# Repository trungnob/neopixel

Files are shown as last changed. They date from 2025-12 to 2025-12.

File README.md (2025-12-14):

# ESP8266 LED Matrix Controller & Pattern Designer

This project drives a **32x32 LED Matrix** (composed of four 8x32 WS2812B panels) using an ESP8266 (Wemos D1 Mini). It features a web-based **Pattern Designer** for creating and uploading custom pixel art and animations.

## Features
- **Hardware Support**: Configured for a 32x32 grid (1024 LEDs) using 4x 8x32 panels in a vertical stack.
- **Web Interface**: 
  - **Control Panel**: Switch between 40+ pre-defined patterns (Rainbow, Fire, Matrix, etc.).
  - **Pattern Designer**: Draw custom pixel art, create animations, and scroll text.
  - **Static Mode**: Display static images (Speed 0).
- **OTA Updates**: Flash new firmware wirelessly.
- **Mechanical Parts**: 3D printable housing for the panels.

## Directory Structure
- `src/`: Firmware source code (C++).
- `web/`: Web interface (`pattern-designer.html`).
- `mechanical/`:
  - `stl/`: 3D printable files (Housing, Mounts).
  - `scad/`: OpenSCAD source files for the housing.
- `scripts/`: Build and utility scripts.

## Getting Started

### 🚀 Quick Start (Recommended)
Run the automated setup script to configure Wi-Fi, install dependencies, and flash the device:
```bash
./scripts/quickstart.sh
```

### Manual Setup
If you prefer to set up everything manually:

### Prerequisites
- Python 3
- `pip`
- `make` (optional, but recommended)

### 1. Setup Environment
Run the bootstrap script to create a virtual environment and install PlatformIO:
```bash
make deps
# Or manually: ./scripts/bootstrap.sh
```

### 2. Configure Secrets
1. Copy the secrets template:
   ```bash
   cp config/secrets.env.example config/secrets.env
   ```
2. Edit `config/secrets.env` and add your Wi-Fi credentials (`WIFI_SSID` and `WIFI_PASSWORD`).
3. Generate OTA credentials:
   ```bash
   make ota-init HOST=192.168.1.130
   ```

### 3. Build and Upload Firmware
**First time (USB):**
Connect your ESP8266 via USB.
```bash
make upload PORT=/dev/ttyUSB0
```
*(Note: `PORT` might vary, e.g., `/dev/ttyACM0`)*

**Subsequent updates (OTA):**
```bash
make upload-ota HOST=192.168.1.130
```

### 4. Run the Pattern Designer
The Pattern Designer runs locally on your computer and communicates with the ESP8266.
```bash
python3 server.py
```
Open your browser to: [http://localhost:8000/pattern-designer.html](http://localhost:8000/pattern-designer.html)

**Note:** Ensure your computer is on the same Wi-Fi network as the ESP8266. The web interface proxies requests to the ESP8266 IP defined in `server.py` (default `192.168.1.130`).

## Mechanical Parts
3D printable files are located in `mechanical/stl/`.
- **Housing**: `8x32_housing_left.stl`, `8x32_housing_right.stl`
- **Stacked Batch**: `8x32_housing_stack.stl` (3x Left Half, matches original production file)
- **Source**: OpenSCAD files in `mechanical/scad/`.

To regenerate the STLs from source:
```bash
make mechanical
```

## Development
- **Build**: `make build`
- **Clean**: `make clean`
- **Monitor Serial**: `make monitor PORT=/dev/ttyUSB0`

## License
MIT License.

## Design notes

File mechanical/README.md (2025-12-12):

# 8×32 LED Panel Housing

3D printable housing for flexible 8×32 LED matrix panels (320mm × 80mm).

Panel Reference

## 📐 Panel Specifications

- **Size**: 8 rows × 32 columns (256 LEDs total)
- **Dimensions**: 320mm × 80mm (~12.6" × 3.15")
- **Thickness**: ~1.5mm flexible PCB
- **Connectors**: Multiple JST connectors along panel

## 🎯 Housing Features

- **Thin profile**: Only 8mm deep
- **Front LED channel**: 2mm shallow groove holds panel flat
- **Wire routing**: Back channels and exit holes for connectors
- **Mounting**: 4× M3 holes at corners for hanging/attaching
- **Weight reduction**: Hollow cavity reduces material use

## 📁 Files

### Full Housing (requires large printer)
- `8x32_panel_housing.scad` - Single piece design (324mm long)
- Requires printer with ≥ 324mm × 84mm build area

### Split Housing (for smaller printers)
- `8x32_housing_split.scad` - Two-piece design (162mm each)
- For printers with < 324mm beds
- Includes alignment pins for easy assembly

## 🖨️ Print Settings

```
Layer Height:    0.2mm
Infill:          20%
Supports:        None
Orientation:     Face down (wire channels facing up)
Material:        PLA or PETG
```

**Full housing**: ~3-4 hours  
**Split housing**: ~2 hours per half

## 🔨 Assembly

### Option 1: Full Housing
1. Print `8x32_panel_housing.scad`
2. Insert LED panel from front
3. Route wires through back holes
4. Mount using corner M3 holes

### Option 2: Split Housing
1. Print both halves from `8x32_housing_split.scad`
2. Insert LED panel into left half
3. Align right half using pins
4. Join with CA glue or epoxy
5. Optional: Add screw through split for strength
6. Route wires and mount

## ⚙️ Customization

Edit the SCAD files to adjust:

```scad
// Panel fit
panel_length = 320;          // Your panel length
panel_width = 80;            // Your panel width

// Wire routing
wire_hole_diameter = 6;      // Connector size
wire_hole_positions = [...]; // Add/move holes

// Housing depth
housing_depth = 8;           // Make deeper if needed

// Mounting holes
mounting_hole_dia = 4;       // M3 = 4mm, M4 = 5mm
```

## 💡 Tips

**If wires don't fit through holes:**
- Increase `wire_hole_diameter` to 8mm or 10mm
- Add more holes at connector positions

**If panel is loose:**
- Add thin foam tape or silicone dots
- Increase `led_channel_depth` slightly

**For wall mounting:**
- Print with 100% infill near mounting holes
- Use M3 × 10mm screws into wall anchors

**For desk stand:**
- Add triangular supports to back
- Use rubber feet to prevent sliding

## 📦 Materials Needed

- PLA or PETG filament (~50g)
- LED panel (8×32, 320mm × 80mm)
- Optional: 4× M3 screws for mounting
- Optional: CA glue (for split version)
- Optional: Foam tape for panel security

## 🎨 Variants You Can Make

1. **Deeper housing** - increase `housing_depth` for electronics
2. **Diffuser mount** - add front lip for acrylic diffuser
3. **Stackable** - add alignment features for multiple panels
4. **Angled mount** - modify for tilted wall display

## 🚀 Quick Start

```bash
# Export full housing
cd /home/trungnob/neopixel/mechanical
openscad -o 8x32_housing.stl 8x32_panel_housing.scad

# Or export split (left half)
openscad -D "is_left_half=true" -o 8x32_left.stl 8x32_housing_split.scad

# Export split (right half)  
openscad -D "is_left_half=false" -o 8x32_right.stl 8x32_housing_split.scad
```

## 📏 Dimensions Reference

| Component | Measurement |
|---|---|
| Panel Length | 320mm (12.59in) |
| Panel Width | 80mm (3.15in) |
| Panel Thickness | ~1.5mm |
| Housing Length | 324mm |
| Housing Width | 84mm |
| Housing Depth | 8mm |
| Weight (printed) | ~40-50g |

Perfect for LED matrix displays, digital signs, or decorative lighting!

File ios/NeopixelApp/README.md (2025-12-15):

# Neopixel iOS App

This folder contains the Swift source files for the **NeopixelApp** iOS application.

## How to use
1. Open Xcode on your Mac.
2. Choose **File → New → Project…** → **App** → **SwiftUI**.
3. Name the project **NeopixelApp** and set the Interface to **SwiftUI**, Life Cycle to **UIKit App Delegate**, Language to **Swift**.
4. When the project is created, replace the automatically generated files with the ones in this folder:
   - `AppDelegate.swift`
   - `SceneDelegate.swift`
   - `ContentView.swift`
   - `PatternGrid.swift`
   - `NetworkManager.swift`
5. Add the `Info.plist` entry `NSAppTransportSecurity` → `NSAllowsArbitraryLoads` = `YES` (or edit the existing Info.plist).
6. Build and run on your iPhone (or Simulator). The app will discover ESP8266 devices via Bonjour (`_neopixel._tcp`) and let you control the LED matrix.

## mDNS on the ESP8266
Add the following snippet to `src/main.cpp` **after** `ArduinoOTA.begin();` and re‑upload the firmware:
```cpp
if (MDNS.begin("neopixel-controller")) {
    MDNS.addService("neopixel", "tcp", 80);
    Serial.println("mDNS responder started");
}
```
The device will appear as `neopixel-controller.local` and be listed automatically in the app.

Enjoy!

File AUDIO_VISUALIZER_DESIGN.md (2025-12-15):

# Audio Visualizer Data Flow

## System Architecture

```
┌─────────────────────────────────────────────────────────────────────────────┐
│                        AUDIO VISUALIZER DATA FLOW                           │
└─────────────────────────────────────────────────────────────────────────────┘

┌──────────────┐
│   YouTube/   │
│   Spotify/   │
│   Any App    │
└──────┬───────┘
       │ Audio Output
       ▼
┌──────────────────────────────────────────────────────────────────────────┐
│                            PipeWire Audio System                          │
│                                                                          │
│  ┌─────────────────────┐                                                 │
│  │  visualizer_sink    │◄─── Apps send audio here (set as default)       │
│  │  (Null Sink)        │                                                 │
│  └──────────┬──────────┘                                                 │
│             │                                                            │
│             │ .monitor (realtime capture)                                │
│             │                                                            │
│             ├───────────────────────────────┐                            │
│             │                               │                            │
│             ▼                               ▼                            │
│  ┌──────────────────────┐     ┌─────────────────────────┐               │
│  │  parec (capture)     │     │  module-loopback        │               │
│  │  --latency-msec=1    │     │  latency_msec=1         │               │
│  └──────────┬───────────┘     └──────────┬──────────────┘               │
│             │                            │                               │
│             │ ◄──── MEASUREMENT POINT    │                               │
│             │       (1.4s includes       │                               │
│             │        human reaction)     │                               │
│             │                            │                               │
└─────────────┼────────────────────────────┼───────────────────────────────┘
              │                            │
              │ Raw PCM Audio              │ Delayed Audio
              ▼                            ▼
┌─────────────────────────┐    ┌─────────────────────────┐
│  lowlatency_visualizer  │    │  HDMI Output            │
│  (Python Script)        │    │  (alsa_output...hdmi)   │
│                         │    │                         │
│  ┌───────────────────┐  │    │  ┌───────────────────┐  │
│  │  FFT Processing   │  │    │  │  Speakers/TV      │  │
│  │  (scipy.fft.rfft) │  │    │  └───────────────────┘  │
│  └─────────┬─────────┘  │    └─────────────────────────┘
│            │            │
│  ┌─────────▼─────────┐  │
│  │  32 Frequency     │  │
│  │  Bins (40-16kHz)  │  │
│  └─────────┬─────────┘  │
│            │            │
│  ┌─────────▼─────────┐  │
│  │  LED Mapping      │  │
│  │  XY() function    │  │
│  └─────────┬─────────┘  │
│            │            │
└────────────┼────────────┘
             │ UDP Packet (3072 bytes)
             ▼
┌─────────────────────────┐
│  ESP8266 (192.168.1.130)│
│  Port 4210              │
│                         │
│  ┌───────────────────┐  │
│  │  FastLED Library  │  │
│  │  WS2812B Driver   │  │
│  └─────────┬─────────┘  │
└────────────┼────────────┘
             │ Data Signal
             ▼
┌─────────────────────────┐
│  32x32 LED Matrix       │
│  (4 × 8x32 Panels)      │
│  1024 WS2812B LEDs      │
└─────────────────────────┘
```

## Latency Measurement

The **1.43 second** was measured using `latency_test.py`:

```
Test data:
1.33s | 0.796 | Music still playing
1.44s | 0.000 | Silence detected
─────────────────────────────────────
Drop time: 1.44 - 1.33 = 0.11 seconds
```

### What the measurement shows:

```
┌─────────────────────────────────────────────────────────────────────┐
│ 0.0s                           1.33s                    1.44s       │
│  │                               │                        │         │
│  │◄─── Human Reaction Time ─────►│◄── Audio Latency ────►│         │
│  │     (ENTER → click pause)     │    (~110ms)           │         │
│  │         ~1.33 seconds         │                        │         │
│  │                               │                        │         │
│  ▼                               ▼                        ▼         │
│ [Press ENTER]              [Click Pause]          [parec sees 0]   │
│              in terminal          on YouTube                        │
└─────────────────────────────────────────────────────────────────────┘
```

### Latency Breakdown

| Component | Latency |
|---|---|
| Human reaction (ENTER → click pause) | ~1330ms |
| **Actual audio latency** | **~110ms** |
| FFT + LED mapping | ~0.2ms |
| UDP over WiFi | ~5-10ms |
| ESP8266 → LEDs | ~30ms |
| **Total audio → LED (theoretical)** | **~150ms** |

## ⚠️ Unresolved Issue: 7 Second Delay

When running `lowlatency_visualizer.py`, there's still a ~7 second delay
from music start/stop to LED response, even though:

- parec captures with ~110ms latency ✓
- FFT processing takes 0.18ms ✓  
- No buffer at startup ✓

The delay might be in:
1. PipeWire's internal routing to visualizer_sink
2. The loopback module buffering
3. Browser audio pipeline

**TODO:** Further investigation needed

## Configuration

To use this setup, run:
```bash
# Set audio output to visualizer
pactl set-default-sink visualizer_sink

# Run the visualizer
python3 lowlatency_visualizer.py --brightness 0.3
```

## Files

- `lowlatency_visualizer.py` - Main visualizer using parec
- `latency_test.py` - Tool to measure audio latency
- `live_visualizer.py` - Alternative using PyAudio

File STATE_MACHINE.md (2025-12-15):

# ESP8266 LED Matrix - State Machine

## Device States & Inputs

```
┌─────────────────────────────────────────────────────────────────────────────┐
│                         ESP8266 LED MATRIX STATE MACHINE                    │
└─────────────────────────────────────────────────────────────────────────────┘

                                    INPUTS
┌─────────────────────────────────────────────────────────────────────────────┐
│  • UDP Packet (port 4210)     - LED frame data (3072 bytes)                 │
│  • HTTP Request               - /set, /setText, /setLayout, /uploadPattern │
│  • OTA Upload                 - Firmware update via ArduinoOTA             │
│  • Timer                      - millis() for animations and timeouts       │
└─────────────────────────────────────────────────────────────────────────────┘

                              STATE DIAGRAM

                         ┌──────────────────┐
                         │     STARTUP      │
                         │   (serverRunning │
                         │     = false)     │
                         └────────┬─────────┘
                                  │
                                  │ WiFi Connected
                                  │ + Server Started
                                  ▼
         ┌────────────────────────────────────────────────────┐
         │                                                    │
         │                  NORMAL MODE                       │
         │              (currentPattern = 0-254)              │
         │                                                    │
         │  ┌────────────────────────────────────────────┐   │
         │  │ loop() {                                   │   │
         │  │   ArduinoOTA.handle()     [~0-50ms]       │   │
         │  │   server.handleClient()   [~0-100ms]      │   │
         │  │   checkUDP()              [~0.1ms]        │   │
         │  │   EVERY_N_MS(20) {                        │   │
         │  │     renderPattern()       [~1-5ms]        │   │
         │  │     FastLED.show()        [~30ms]         │   │
         │  │   }                                       │   │
         │  │ }                                         │   │
         │  │ Total: 30-180ms per loop                  │   │
         │  └────────────────────────────────────────────┘   │
         │                                                    │
         └───────────────────────┬────────────────────────────┘
                                 │
              ┌──────────────────┼──────────────────┐
              │                  │                  │
              ▼                  ▼                  ▼
    ┌─────────────────┐ ┌───────────────┐ ┌─────────────────┐
    │ HTTP: /set?p=N  │ │  UDP Packet   │ │   OTA Upload    │
    │                 │ │   Received    │ │                 │
    └────────┬────────┘ └───────┬───────┘ └────────┬────────┘
             │                  │                   │
             │                  │                   │
             ▼                  ▼                   ▼
    ┌─────────────────┐ ┌───────────────────┐ ┌─────────────┐
    │ Set Pattern     │ │ Switch to         │ │ Reboot      │
    │ (0-254)         │ │ Streaming Mode    │ │ after flash │
    └────────┬────────┘ │ (pattern=255)     │ └─────────────┘
             │          └───────┬───────────┘
             │                  │
             ▼                  ▼
         ┌──────────────────────────────────────────────────┐
         │                                                   │
         │               STREAMING MODE                      │
         │             (currentPattern = 255)                │
         │                                                   │
         │  ┌────────────────────────────────────────────┐  │
         │  │ loop() {                                   │  │
         │  │   ArduinoOTA.handle()     [~0-50ms] ❌     │  │
         │  │   server.handleClient()   [~0-100ms] ❌    │  │
         │  │   checkUDP() {            [~0.1ms]        │  │
         │  │     read packet into leds                 │  │
         │  │     drain extra packets   [~0.1ms/pkt]    │  │
         │  │     FastLED.show()        [~30ms]         │  │
         │  │   }                                       │  │
         │  │ }                                         │  │
         │  │ Target: ~30ms per frame (~33 FPS max)     │  │
         │  └────────────────────────────────────────────┘  │
         │                                                   │
         │  PROBLEM: OTA/HTTP still run, adding latency!     │
         │                                                   │
         └───────────────────────┬───────────────────────────┘
                                 │
                                 │ No UDP for 5 seconds (timeout)
                                 │ OR HTTP: /set?p=N
                                 ▼
                    ┌────────────────────────┐
                    │  Return to NORMAL MODE │
                    │  (currentPattern = N)  │
                    └────────────────────────┘

                         PATTERNS (0-254)
┌─────────────────────────────────────────────────────────────────────────────┐
│  0-99:    Built-in animations (rainbow, fire, plasma, etc)                  │
│  100-199: Special effects (clock, text scroll, etc)                        │
│  200:     IP + Clock display (default on boot)                             │
│  255:     UDP Streaming mode (external control)                            │
└─────────────────────────────────────────────────────────────────────────────┘

                     FINAL IMPLEMENTATION
┌─────────────────────────────────────────────────────────────────────────────┐
│                                                                             │
│  ┌─────────────────┐                          ┌─────────────────────┐      │
│  │   NORMAL MODE   │  HTTP: /stream           │   STREAMING MODE    │      │
│  │  (pattern 0-254)│ ─────────────────────────▶ (pattern 255)       │      │
│  │                 │                          │                     │      │
│  │  • HTTP ✓       │                          │  • HTTP ✗ (skipped) │      │
│  │  • OTA ✓        │                          │  • OTA ✗ (skipped)  │      │
│  │  • Animations   │◀──────────────────────── │  • ~30 FPS max      │      │
│  │                 │  UDP: "EXIT" or timeout  │                     │      │
│  └─────────────────┘                          └─────────────────────┘      │
│                                                                             │
└─────────────────────────────────────────────────────────────────────────────┘

## Usage

```python
# Enter streaming mode
requests.get("http://192.168.1.130/stream")

# Send LED frames
sock.sendto(led_data, ("192.168.1.130", 4210))

# Exit streaming mode
sock.sendto(b"EXIT", ("192.168.1.130", 4210))
```

## Summary

| State | Enter | Exit | FPS |
|---|---|---|-----|
| Normal | Boot or EXIT | HTTP `/stream` | N/A |
| Streaming | HTTP `/stream` | UDP `EXIT` or 5s timeout | ~30 |

┌─────────────────────────────────────────────────────────────────────────────┐
│                                                                             │
│                              ┌─────────────┐                                │
│                              │   STARTUP   │                                │
│                              │  WiFi Init  │                                │
│                              └──────┬──────┘                                │
│                                     │                                       │
│                                     │ WiFi Connected                        │
│                                     ▼                                       │
│  ┌─────────────────────────────────────────────────────────────────────┐   │
│  │                         NORMAL MODE                                  │   │
│  │                      (currentPattern = 0-254)                        │   │
│  │                                                                      │   │
│  │   INPUTS PROCESSED:                                                  │   │
│  │   ├── ArduinoOTA.handle()    [Check for firmware update]            │   │
│  │   ├── server.handleClient()  [Check for HTTP requests]              │   │
│  │   ├── udp.parsePacket()      [Check for UDP packets]                │   │
│  │   └── renderPattern()        [Run current animation]                │   │
│  │                                                                      │   │
│  │   LOOP TIME: 30-180ms (variable due to HTTP/OTA overhead)           │   │
│  │   EFFECTIVE FPS: ~5-30 FPS                                          │   │
│  └──────────────────────────────────┬──────────────────────────────────┘   │
│                                     │                                       │
│                                     │ UDP Packet Received                   │
│                                     │ (any LED data, 3072 bytes)            │
│                                     ▼                                       │
│  ┌─────────────────────────────────────────────────────────────────────┐   │
│  │                       STREAMING MODE                                 │   │
│  │                     (currentPattern = 255)                           │   │
│  │                                                                      │   │
│  │   INPUTS PROCESSED:                                                  │   │
│  │   ├── udp.parsePacket()      [Check for UDP packets]      ✓ FAST    │   │
│  │   └── FastLED.show()         [Update LED strip]           ✓ NEEDED  │   │
│  │                                                                      │   │
│  │   INPUTS SKIPPED (during active streaming):                          │   │
│  │   ├── ArduinoOTA.handle()    ✗ SKIP (saves 0-50ms)                  │   │
│  │   └── server.handleClient()  ✗ SKIP (saves 0-100ms)                 │   │
│  │                                                                      │   │
│  │   LOOP TIME: ~30ms (consistent)                                     │   │
│  │   EFFECTIVE FPS: ~33 FPS (maximum for 1024 LEDs)                    │   │
│  └──────────────────────────────────┬──────────────────────────────────┘   │
│                                     │                                       │
│                  ┌──────────────────┼──────────────────┐                   │
│                  │                  │                  │                   │
│                  ▼                  ▼                  ▼                   │
│         ┌──────────────┐  ┌──────────────┐  ┌──────────────────┐          │
│         │ UDP: "EXIT"  │  │ UDP Timeout  │  │ Brief HTTP Check │          │
│         │  (4 bytes)   │  │  (5 seconds) │  │ (every 500ms)    │          │
│         └──────┬───────┘  └──────┬───────┘  └────────┬─────────┘          │
│                │                 │                   │                     │
│                └─────────────────┴───────────────────┘                     │
│                                  │                                         │
│                                  ▼                                         │
│                         Return to NORMAL MODE                              │
│                                                                             │
└─────────────────────────────────────────────────────────────────────────────┘

                           UDP PACKET TYPES
┌─────────────────────────────────────────────────────────────────────────────┐
│                                                                             │
│  ┌────────────────────────────────────────────────────────────────────┐    │
│  │  LED DATA PACKET (3072 bytes)                                      │    │
│  │  ───────────────────────────────                                   │    │
│  │  Format: [R0][G0][B0][R1][G1][B1]...[R1023][G1023][B1023]          │    │
│  │  Effect: Update LEDs, enter/stay in STREAMING MODE                 │    │
│  └────────────────────────────────────────────────────────────────────┘    │
│                                                                             │
│  ┌────────────────────────────────────────────────────────────────────┐    │
│  │  EXIT PACKET (4 bytes)                                             │    │
│  │  ─────────────────────                                             │    │
│  │  Format: "EXIT" (0x45 0x58 0x49 0x54)                              │    │
│  │  Effect: Return to NORMAL MODE (enable HTTP/OTA)                   │    │
│  └────────────────────────────────────────────────────────────────────┘    │
│                                                                             │
│  ┌────────────────────────────────────────────────────────────────────┐    │
│  │  STATS REQUEST (5 bytes) - Optional                                │    │
│  │  ───────────────────────                                           │    │
│  │  Format: "STATS" (0x53 0x54 0x41 0x54 0x53)                        │    │
│  │  Effect: Reply with JSON stats (received/displayed/dropped)        │    │
│  └────────────────────────────────────────────────────────────────────┘    │
│                                                                             │
└─────────────────────────────────────────────────────────────────────────────┘

                      PYTHON CLIENT USAGE
┌─────────────────────────────────────────────────────────────────────────────┐
│                                                                             │
│  # Normal streaming (just send LED data)                                    │
│  sock.sendto(led_data, (ESP_IP, 4210))                                     │
│                                                                             │
│  # Exit streaming mode (to enable OTA or web UI)                           │
│  sock.sendto(b"EXIT", (ESP_IP, 4210))                                      │
│  time.sleep(0.5)  # Wait for mode switch                                   │
│  # Now HTTP and OTA work normally                                          │
│                                                                             │
│  # Resume streaming                                                         │
│  sock.sendto(led_data, (ESP_IP, 4210))  # Auto-enters streaming mode       │
│                                                                             │
└─────────────────────────────────────────────────────────────────────────────┘
```

## Summary Table

| State | OTA | HTTP | UDP | Loop Time | FPS |
|-------|-----|------|-----|-----------|-----|
| Normal | ✓ | ✓ | ✓ | 30-180ms | 5-30 |
| **Streaming (proposed)** | ✗ | ✗* | ✓ | **~30ms** | **~33** |

*HTTP checked briefly every 500ms during streaming for stats endpoint

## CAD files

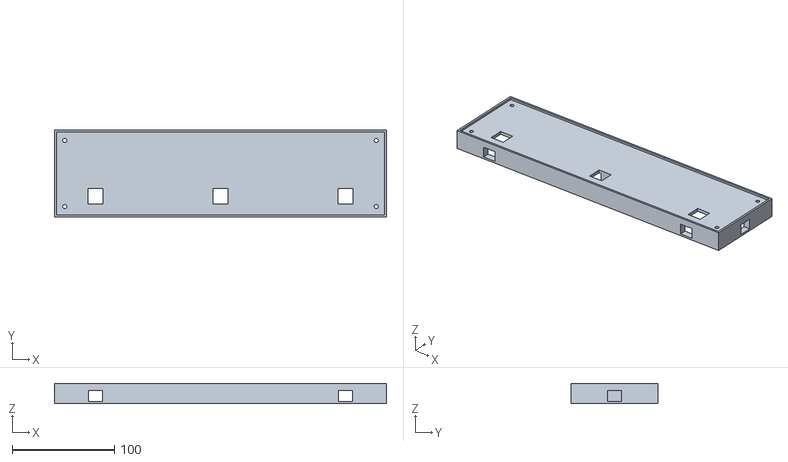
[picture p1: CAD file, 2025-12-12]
mechanical/8x32_right.stl
324.0 x 84.6 x 20.0

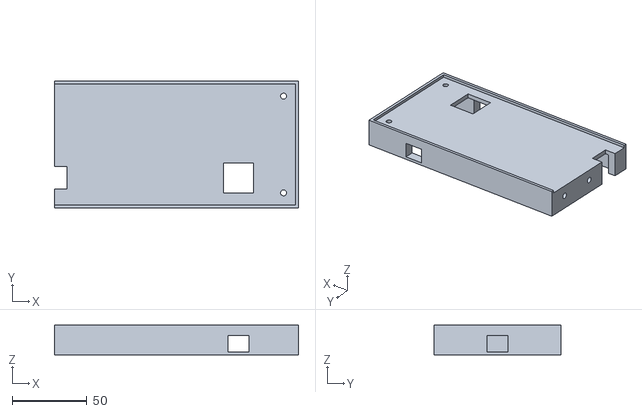
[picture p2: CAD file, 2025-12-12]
mechanical/stl/8x32_housing_right.stl
163.0 x 84.6 x 20.0

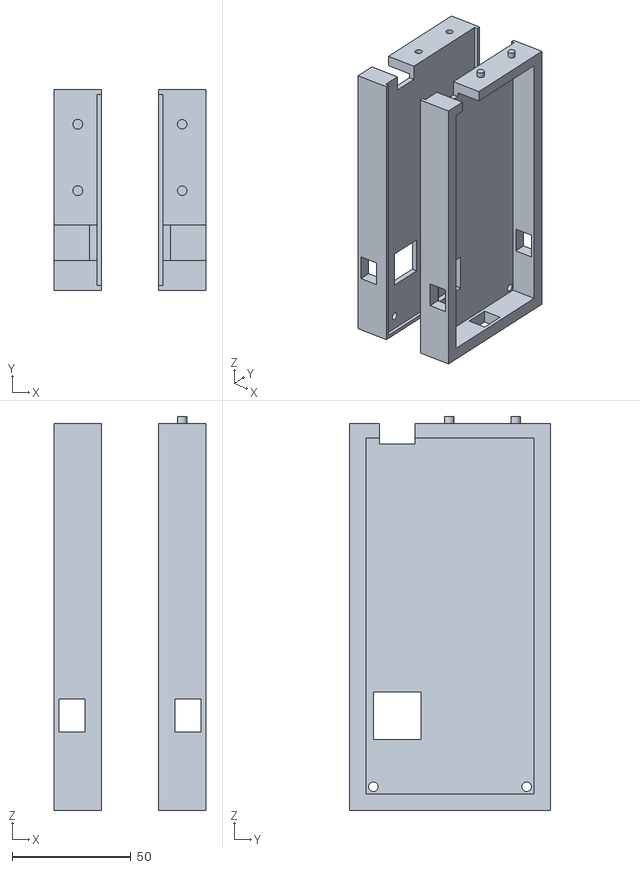
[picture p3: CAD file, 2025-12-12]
mechanical/stl/8x32_housing_all.stl
64.0 x 84.6 x 166.0

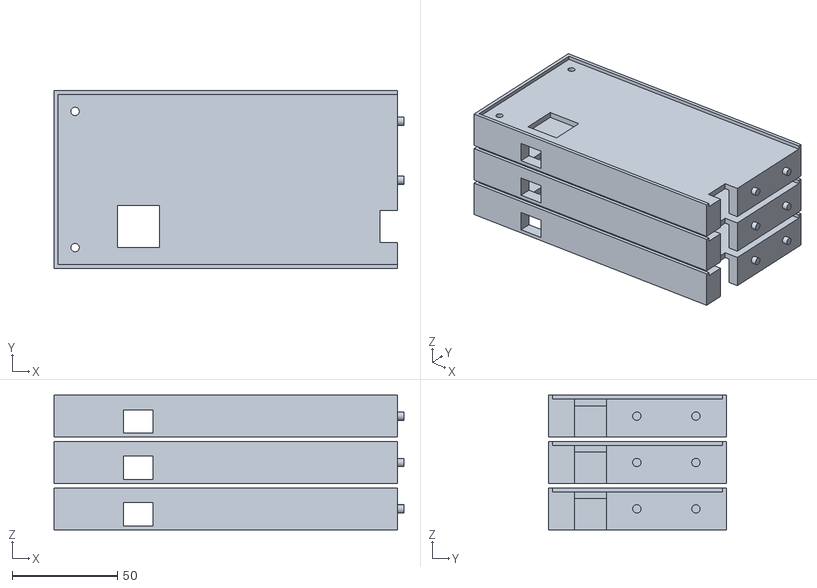
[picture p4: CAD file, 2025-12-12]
mechanical/stl/8x32_housing_stack.stl
166.0 x 84.6 x 64.0

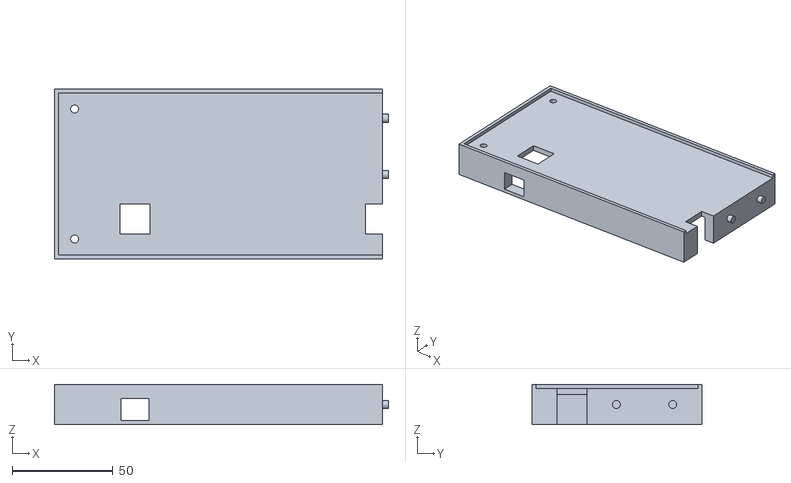
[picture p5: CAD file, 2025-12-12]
mechanical/8x32_housing_left_v2.stl
166.0 x 84.6 x 20.0

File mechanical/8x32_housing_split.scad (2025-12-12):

/*
 * 8x32 LED Panel Housing - SPLIT VERSION
 * For printers with < 324mm build volume
 * Splits 324mm housing into 2× 162mm pieces with alignment
 */

// Include or copy the base design parameters
panel_length = 320;
panel_width = 80.6;
panel_thickness = 1.5;
housing_length = panel_length + 4;
housing_width = panel_width + 4;
housing_depth = 20; // Increased from 16mm to 20mm for more wire space
wall_thickness = 2; // Restored to 2mm (was 7mm, causing missing wall)
led_channel_depth = 2;
led_channel_width = panel_width;
led_channel_length = panel_length;
// ADJUST THIS PARAMETER to change the square hole size
wire_hole_size = 20; 
wire_channel_width = 14; // Increased from 10mm to 14mm
wire_channel_depth = 11; // Deeper wire channels
mounting_hole_dia = 4;
mounting_hole_inset = 10;

// Split parameters
split_position = housing_length / 2;  // Split in middle
alignment_pin_dia = 4;
alignment_pin_depth = 4;
alignment_pin_tolerance = 0.2;

module half_housing(is_left_half = true) {
    difference() {
        union() {
            // Half of the main housing
            intersection() {
                // Full housing (matching main design)
                difference() {
                    cube([housing_length, housing_width, housing_depth]);
                    
                    // LED channel
                    translate([wall_thickness, wall_thickness, housing_depth - led_channel_depth])
                        cube([led_channel_length, led_channel_width, led_channel_depth + 0.1]);
                    
                    // ===== WIRE HOLES through LED panel surface =====
                    // Y position: 2cm (20mm) from bottom edge
                    wire_y_pos = 20;
                    
                    // Left hole - 4cm (40mm) from left edge
                    if (is_left_half) {
                        translate([40, wire_y_pos, -0.1])
                            translate([-wire_hole_size/2, -wire_hole_size/2, 0]) // Center the square
                            cube([wire_hole_size, wire_hole_size, housing_depth - led_channel_depth + 0.2]);
                    }
                    // Right hole - 4cm (40mm) from right edge
                    else {
                        translate([housing_length - 40, wire_y_pos, -0.1])
                            translate([-wire_hole_size/2, -wire_hole_size/2, 0])
                            cube([wire_hole_size, wire_hole_size, housing_depth - led_channel_depth + 0.2]);
                    }

                    // Center hole - 16cm (approx middle). Using exact center (162mm) to align with split.
                    // User requested to keep this at 15mm while others are 20mm
                    translate([housing_length / 2, wire_y_pos, -0.1])
                        translate([-15/2, -15/2, 0])
                        cube([15, 15, housing_depth - led_channel_depth + 0.2]);
                    
                    // Weight reduction
                    // Increased depth to leave only 5mm of material at the front
                    // Reduced border width: Offset 5mm (was 15mm) -> 7mm border
                    // SPLIT into two parts to create a solid rib at the center (to hold alignment pins)
                    
                    // Part 1 (Left side)
                    translate([wall_thickness + 5, wall_thickness + 5, -0.1])
                        cube([split_position - (wall_thickness + 5) - 5, // Stop 5mm before center
                              housing_width - 2*wall_thickness - 10,
                              housing_depth - 5]);
                              
                    // Part 2 (Right side)
                    translate([split_position + 5, wall_thickness + 5, -0.1]) // Start 5mm after center
                        cube([housing_length - split_position - 5 - (wall_thickness + 5),
                              housing_width - 2*wall_thickness - 10,
                              housing_depth - 5]);
                    
                    // ===== SIDE WIRE CHANNELS (N/S/E/W) =====
                    // Allow wires to pass between panels through the walls
                    // Extended to 25mm to cut through the solid border into the hollow center
                    // Moved to Z=2 to make them "holes" instead of "slots" (Solid bottom border)
                    
                    // North/South Channels (Top/Bottom walls)
                    // Removed center channel (housing_length/2) as requested
                    for (x_pos = [40, housing_length - 40]) {
                         // Bottom wall (South)
                         translate([x_pos - wire_channel_width/2, -0.1, 2])
                            cube([wire_channel_width, 25, wire_channel_depth]);
                         
                         // Top wall (North)
                         translate([x_pos - wire_channel_width/2, housing_width - 25, 2])
                            cube([wire_channel_width, 25.1, wire_channel_depth]);
                    }

                    // East/West Channels (Left/Right walls)
                    // Left wall (West)
                    translate([-0.1, housing_width/2 - wire_channel_width/2, 2])
                        cube([25, wire_channel_width, wire_channel_depth]);

                    // Right wall (East)
                    translate([housing_length - 25, housing_width/2 - wire_channel_width/2, 2])
                        cube([25.1, wire_channel_width, wire_channel_depth]);


                    // Mounting holes
                    if (is_left_half) {
                        translate([mounting_hole_inset, mounting_hole_inset, -0.1])
                            cylinder(h=housing_depth + 0.2, d=mounting_hole_dia, $fn=24);
                        translate([mounting_hole_inset, housing_width - mounting_hole_inset, -0.1])
                            cylinder(h=housing_depth + 0.2, d=mounting_hole_dia, $fn=24);
                    } else {
                        translate([housing_length - mounting_hole_inset, mounting_hole_inset, -0.1])
                            cylinder(h=housing_depth + 0.2, d=mounting_hole_dia, $fn=24);
                        translate([housing_length - mounting_hole_inset, housing_width - mounting_hole_inset, -0.1])
                            cylinder(h=housing_depth + 0.2, d=mounting_hole_dia, $fn=24);
                    }
                }
                
                // Cut to half
                if (is_left_half) {
                    cube([split_position + 1, housing_width, housing_depth]);
                } else {
                    translate([split_position - 1, 0, 0])
                        cube([housing_length - split_position + 1, housing_width, housing_depth]);
                }
            }
            
            // Add alignment pins (on left half)
            if (is_left_half) {
                // Pins stick out from the split face
                // Reverted to center (housing_depth/2) now that we have a solid rib
                translate([split_position, 42, housing_depth/2])
                    rotate([0, 90, 0])
                    cylinder(h=alignment_pin_depth, d=alignment_pin_dia, $fn=24);
                
                translate([split_position, 70, housing_depth/2])
                    rotate([0, 90, 0])
                    cylinder(h=alignment_pin_depth, d=alignment_pin_dia, $fn=24);
            }
        }
        
        // Add alignment holes (on right half)
        if (!is_left_half) {
            translate([split_position - 1, 42, housing_depth/2])
                rotate([0, 90, 0])
                cylinder(h=alignment_pin_depth + 1, 
                        d=alignment_pin_dia + alignment_pin_tolerance, 
                        $fn=24);
            
            translate([split_position - 1, 70, housing_depth/2])
                rotate([0, 90, 0])
                cylinder(h=alignment_pin_depth + 1, 
                        d=alignment_pin_dia + alignment_pin_tolerance, 
                        $fn=24);
        }
    }
}

// ========== RENDER ==========

// ========== RENDER ==========

// Render Mode:
// 0 = Left Half (for printing)
// 1 = Right Half (for printing)
// 2 = Full Assembly (for preview)
render_mode = 2; 

if (render_mode == 0) {
    half_housing(is_left_half = true);
} else if (render_mode == 1) {
    half_housing(is_left_half = false);
} else {
    // Full Assembly
    // Render both halves in place to show the complete panel
    half_housing(is_left_half = true);
    half_housing(is_left_half = false);
}
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

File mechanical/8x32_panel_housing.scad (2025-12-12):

/*
 * 8x32 LED Panel Housing
 * Compact housing for flexible 8x32 LED matrix panel
 *
 * Features:
 * - Front channel to hold LED panel flush
 * - 3 wire holes through LED panel surface (for connectors to pass through)
 * - 4× M3 mounting holes at corners
 * - Thin 8mm profile for space efficiency
 */

// ========== CONFIGURATION ==========

// LED Panel dimensions (from photo: 12.59in x 3.15in ≈ 320mm x 80mm)
panel_length = 320;      // 12.59 inches
panel_width = 80;        // 3.15 inches  
panel_thickness = 1.5;   // Flexible PCB thickness

// Housing dimensions
housing_length = panel_length + 4;  // 324mm (add small margin)
housing_width = panel_width + 4;    // 84mm
housing_depth = 8;                   // Shallow profile
wall_thickness = 2;

// Front LED channel (shallow groove to hold panel)
led_channel_depth = 2;      // Just enough to hold panel flat
led_channel_width = panel_width;
led_channel_length = panel_length;

// Wire routing
wire_hole_diameter = 6;     // For connector pass-through
wire_channel_width = 10;    // Channel width for wires
wire_channel_depth = 3;     // Back routing depth

// Mounting holes (for hanging/attaching)
mounting_hole_dia = 4;      // M3 screw holes
mounting_hole_inset = 10;   // Distance from edges

// ========== MAIN HOUSING ==========

module led_panel_housing() {
    difference() {
        // Main body
        cube([housing_length, housing_width, housing_depth]);
        
        // ===== FRONT: LED panel channel (shallow) =====
        translate([wall_thickness, wall_thickness, housing_depth - led_channel_depth])
            cube([led_channel_length, 
                  led_channel_width, 
                  led_channel_depth + 0.1]);  // Goes to top surface
        
        // ===== WIRE HOLES through LED panel surface (green area) =====
        // 3 holes in the bottom of LED channel so connectors can pass through
        
        // Left hole (for left connector)
        translate([housing_length * 0.25, housing_width/2, -0.1])
            cylinder(h=housing_depth - led_channel_depth + 0.2, d=wire_hole_diameter, $fn=32);
        
        // Center hole (for middle connector)
        translate([housing_length * 0.50, housing_width/2, -0.1])
            cylinder(h=housing_depth - led_channel_depth + 0.2, d=wire_hole_diameter, $fn=32);
        
        // Right hole (for right connector)
        translate([housing_length * 0.75, housing_width/2, -0.1])
            cylinder(h=housing_depth - led_channel_depth + 0.2, d=wire_hole_diameter, $fn=32);
        
        // ===== Weight reduction cavity (back side) =====
        translate([wall_thickness + 15,
                  wall_thickness + 15,
                  -0.1])
            cube([housing_length - 2*wall_thickness - 30,
                  housing_width - 2*wall_thickness - 30,
                  wall_thickness + 0.1]);
        
        // ===== Mounting holes (corners for hanging) =====
        // Top left
        translate([mounting_hole_inset, mounting_hole_inset, -0.1])
            cylinder(h=housing_depth + 0.2, d=mounting_hole_dia, $fn=24);
        
        // Top right
        translate([housing_length - mounting_hole_inset, mounting_hole_inset, -0.1])
            cylinder(h=housing_depth + 0.2, d=mounting_hole_dia, $fn=24);
        
        // Bottom left
        translate([mounting_hole_inset, housing_width - mounting_hole_inset, -0.1])
            cylinder(h=housing_depth + 0.2, d=mounting_hole_dia, $fn=24);
        
        // Bottom right
        translate([housing_length - mounting_hole_inset, housing_width - mounting_hole_inset, -0.1])
            cylinder(h=housing_depth + 0.2, d=mounting_hole_dia, $fn=24);
    }
}

// ========== LED PANEL VISUALIZATION (optional) ==========
module led_panel_visual() {
    color("darkgreen", 0.8)
    translate([wall_thickness, 
              wall_thickness, 
              housing_depth - led_channel_depth + 0.5])
    cube([panel_length, panel_width, 0.5]);
    
    // LED positions (8 rows x 32 columns)
    led_spacing_x = panel_length / 32;
    led_spacing_y = panel_width / 8;
    
    for (row = [0:7]) {
        for (col = [0:31]) {
            color("gold", 0.6)
            translate([wall_thickness + col * led_spacing_x + led_spacing_x/2,
                      wall_thickness + row * led_spacing_y + led_spacing_y/2,
                      housing_depth - 0.5])
                cylinder(h=1, d=3, $fn=6);
        }
    }
}

// ========== RENDER ==========

// Main housing
led_panel_housing();

// LED panel visualization (uncomment to see LED layout)
// led_panel_visual();

// ========== EXPORT NOTES ==========
/*
 * DIMENSIONS:
 * - Housing: 324mm (L) × 84mm (W) × 8mm (D)
 * - Panel fit: 320mm × 80mm × 1.5mm
 * - Weight: ~40-50g (at 20% infill)
 *
 * FEATURES:
 * - Front LED channel: 2mm deep to hold panel
 * - 3× wire holes in LED panel surface (connectors pass through to back)
 * - 4× M3 mounting holes at corners  
 * - Thin profile (8mm total depth)
 *
 * PRINTING:
 * - Layer height: 0.2mm
 * - Infill: 20%
 * - Supports: None needed (print face-down)
 * - Material: PLA or PETG
 * - Print time: ~3-4 hours
 * - NOTE: 324mm length exceeds many printer beds!
 *
 * SPLITTING FOR SMALLER PRINTERS:
 * If your printer bed is < 324mm, you can:
 * 1. Split into 2× 162mm sections
 * 2. Add alignment pins/holes at the split
 * 3. Join with glue or screws after printing
 *
 * ASSEMBLY:
 * 1. Place LED panel in front channel (LEDs facing up)
 * 2. Thread wires/connectors through the 3 holes from top
 * 3. Wires exit from the back/bottom
 * 4. Mount using corner M3 holes (screws or wall anchors)
 *
 * CUSTOMIZATION:
 * - Adjust wire_hole_diameter for your connectors
 * - Add more wire holes if needed
 * - Modify housing_depth for deeper cavity
 * - Add edge lips/clips if panel needs securing
 *
 * EXPORT STL:
 * openscad -o 8x32_housing.stl 8x32_panel_housing.scad
 */

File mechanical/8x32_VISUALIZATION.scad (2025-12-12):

/*
 * 8x32 LED Panel Housing - VISUALIZATION MODE
 * This version shows a cutaway so you can see the wire holes clearly
 */

// Include all the same parameters
panel_length = 320;
panel_width = 80;
panel_thickness = 1.5;
housing_length = panel_length + 4;  // 324mm
housing_width = panel_width + 4;    // 84mm
housing_depth = 8;
wall_thickness = 2;
led_channel_depth = 2;
led_channel_width = panel_width;
led_channel_length = panel_length;
wire_hole_diameter = 6;
mounting_hole_dia = 4;
mounting_hole_inset = 10;

// CUTAWAY VIEW - shows internal structure
module cutaway_housing() {
    difference() {
        // Original housing
        difference() {
            cube([housing_length, housing_width, housing_depth]);
            
            // LED panel channel (front/top)
            translate([wall_thickness, wall_thickness, housing_depth - led_channel_depth])
                cube([led_channel_length, led_channel_width, led_channel_depth + 0.1]);
            
            // ===== 3 WIRE HOLES IN BACK WALL =====
            // Left hole
            translate([housing_length * 0.25, -0.1, housing_depth/2])
                rotate([-90, 0, 0])
                cylinder(h=wall_thickness + 0.2, d=wire_hole_diameter, $fn=32);
            
            // Center hole
            translate([housing_length * 0.50, -0.1, housing_depth/2])
                rotate([-90, 0, 0])
                cylinder(h=wall_thickness + 0.2, d=wire_hole_diameter, $fn=32);
            
            // Right hole
            translate([housing_length * 0.75, -0.1, housing_depth/2])
                rotate([-90, 0, 0])
                cylinder(h=wall_thickness + 0.2, d=wire_hole_diameter, $fn=32);
            
            // Weight reduction
            translate([wall_thickness + 15, wall_thickness + 15, -0.1])
                cube([housing_length - 2*wall_thickness - 30,
                      housing_width - 2*wall_thickness - 30,
                      wall_thickness + 0.1]);
            
            // Mounting holes
            translate([mounting_hole_inset, mounting_hole_inset, -0.1])
                cylinder(h=housing_depth + 0.2, d=mounting_hole_dia, $fn=24);
            translate([housing_length - mounting_hole_inset, mounting_hole_inset, -0.1])
                cylinder(h=housing_depth + 0.2, d=mounting_hole_dia, $fn=24);
            translate([mounting_hole_inset, housing_width - mounting_hole_inset, -0.1])
                cylinder(h=housing_depth + 0.2, d=mounting_hole_dia, $fn=24);
            translate([housing_length - mounting_hole_inset, housing_width - mounting_hole_inset, -0.1])
                cylinder(h=housing_depth + 0.2, d=mounting_hole_dia, $fn=24);
        }
        
        // CUT AWAY HALF to show interior
        translate([-1, housing_width/2, -1])
            cube([housing_length + 2, housing_width/2 + 2, housing_depth + 2]);
    }
}

// Show wire hole positions with colored markers
module wire_hole_markers() {
    // Left hole marker (RED)
    color("red", 0.8)
    translate([housing_length * 0.25, 0, housing_depth/2])
        rotate([-90, 0, 0])
        cylinder(h=5, d=wire_hole_diameter + 2, $fn=32);
    
    // Center hole marker (GREEN)
    color("green", 0.8)
    translate([housing_length * 0.50, 0, housing_depth/2])
        rotate([-90, 0, 0])
        cylinder(h=5, d=wire_hole_diameter + 2, $fn=32);
    
    // Right hole marker (BLUE)
    color("blue", 0.8)
    translate([housing_length * 0.75, 0, housing_depth/2])
        rotate([-90, 0, 0])
        cylinder(h=5, d=wire_hole_diameter + 2, $fn=32);
}

// RENDER
cutaway_housing();
wire_hole_markers();

// Add text labels
color("white")
translate([housing_length * 0.25 - 10, -10, housing_depth/2])
    text("LEFT", size=8);

color("white")
translate([housing_length * 0.50 - 15, -10, housing_depth/2])
    text("CENTER", size=8);

color("white")
translate([housing_length * 0.75 - 12, -10, housing_depth/2])
    text("RIGHT", size=8);

/*
 * VIEWING INSTRUCTIONS:
 * 
 * In OpenSCAD:
 * 1. Press F5 to preview
 * 2. Use mouse to rotate view
 * 3. Look at the BACK EDGE (narrow 84mm edge at y=0)
 * 4. You'll see 3 colored cylinders showing wire holes:
 *    - RED = Left hole (at 25%)
 *    - GREEN = Center hole (at 50%)
 *    - BLUE = Right hole (at 75%)
 * 
 * The cutaway shows the interior so you can see:
 * - Front LED channel (top surface)
 * - 3 wire holes going through back wall
 * - Mounting holes at corners
 */

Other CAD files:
mechanical/8x32_left.stl
mechanical/stl/8x32_housing_left.stl
mechanical/8x32_housing_right_v3.stl
mechanical/archive/8x32_left.stl
mechanical/8x32_housing_right_v2.stl
mechanical/archive/8x32_housing_right_v3.stl
mechanical/archive/8x32_housing_left_v3.stl
mechanical/scad/8x32_housing.scad

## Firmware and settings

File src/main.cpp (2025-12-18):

#include "pattern_list.h"
#include "patterns.h"
#include <Arduino.h>
#include <ArduinoOTA.h>
#include <ESP8266WebServer.h>
#include <ESP8266WiFi.h>
#include <FastLED.h>
#include <WiFiUdp.h>
#include <time.h>

#ifndef OTA_PASSWORD
#error                                                                         \
    "OTA_PASSWORD is missing. Run `make ota-init` to generate config/ota.env or set OTA_PASSWORD in your environment."
#endif

#ifndef WIFI_SSID
#error "WIFI_SSID is missing. Define it via build flags or secrets header."
#endif

#ifndef WIFI_PASSWORD
#error "WIFI_PASSWORD is missing. Define it via build flags or secrets header."
#endif

#define LED_PIN D4
#define MAX_LEDS 2048 // Support up to 8 panels (8 * 256 = 2048)
#define BRIGHTNESS 76
#define LED_TYPE WS2812B
#define COLOR_ORDER GRB

CRGB leds[MAX_LEDS];
ESP8266WebServer server(80);
WiFiUDP udp;
#define UDP_PORT 4210
unsigned long lastUdpPacketTime = 0;
const unsigned long UDP_TIMEOUT =
    5000; // Switch back after 5s of silence? Optional.

// Layout Presets
enum LayoutType {
  LAYOUT_9X144_ROW_ZIGZAG = 0, // Original: 9 rows × 144 cols, row-wise zigzag
  LAYOUT_8X32_COL_ZIGZAG = 1,  // Single: 8 rows × 32 cols, column-wise zigzag
  LAYOUT_32X32_MULTI_PANEL =
      2 // Multi: 32×32 (4× 8×32 panels stacked vertically)
};

// Current layout configuration (changeable at runtime)
int currentLayout = LAYOUT_32X32_MULTI_PANEL;
int numPanels = 4;     // Default to 4 panels
int panelsWide = 1;    // Default to 1 panel wide (vertical stack)
int GRID_WIDTH = 32;   // 32
int GRID_HEIGHT = 32;  // 32
int activeLeds = 1024; // 4 * 256

// Layout presets configuration
struct LayoutConfig {
  int width;
  int height;
  int totalLeds;
  const char *name;
};

const LayoutConfig layouts[] = {
    {32, 8, 256, "Nx8x32 Multi-Panel"} // Default to N=1 (8x32)
};

// Physical dimensions for aspect-ratio-aware patterns
// Defaulting to 1:1 spacing for 8x32 panels
float LED_SPACING_H = 10.0;
float LED_SPACING_V = 10.0;
float ASPECT_RATIO = 1.0;

// XY function is now in patterns.h (handles both layouts)

// State variables
int currentPattern = 200; // Default to IP + Clock
uint8_t hue = 0;
String scrollText = "HELLO WORLD"; // Global variables
int scrollOffset = 0;
int currentMode = 0;
int scrollSpeed = 20; // Default speed (1-100)

// UDP Stats for debugging
unsigned long udpPacketsReceived = 0;
unsigned long udpPacketsDisplayed = 0;
unsigned long udpStatsLastPrint = 0;

// State Machine Timers
unsigned long lastActivityTime = 0; // Last user interaction or state change
const unsigned long IDLE_TIMEOUT = 60000; // 60 seconds to auto-stream

// Timing profiling (in microseconds)
unsigned long timeParsePacket = 0;
unsigned long timeReadPacket = 0;
unsigned long timeDrainLoop = 0;
unsigned long timeFastLEDShow = 0;
unsigned long timeLoopTotal = 0;
unsigned long timingSamples = 0;

// Custom pattern storage (for pattern designer)
CRGB customPattern[MAX_LEDS];
bool hasCustomPattern = false;

// Font data is now in patterns/font.cpp

// HTML Page
const char htmlPage[] PROGMEM = R"=====(
<!DOCTYPE html>
<html>
<head>
  <meta name="viewport" content="width=device-width, initial-scale=1">
  <style>
    body { font-family: sans-serif; text-align: center; padding: 20px; background: #222; color: #fff; }
    button { display: block; width: 100%; padding: 15px; margin: 10px 0; font-size: 18px; border: none; border-radius: 5px; cursor: pointer; }
    input { padding: 10px; font-size: 16px; width: 60px; text-align: center; }
    .control-group { margin: 20px 0; padding: 15px; background: #333; border-radius: 10px; }
    .rainbow { background: linear-gradient(90deg, red, orange, yellow, green, blue, indigo, violet); color: black; }
    .red { background-color: #ff4444; color: white; }
    .green { background-color: #44ff44; color: black; }
    .blue { background-color: #4444ff; color: white; }
    .cool { background: linear-gradient(45deg, #ff00cc, #3333ff); color: white; }
    .fire { background: linear-gradient(to right, #ff0000, #ffff00); color: black; }
    .special { background: linear-gradient(to right, #00ffff, #ff00ff); color: black; }
    .off { background-color: #555; color: white; }

    /* Tab styles */
    .tabs { display: flex; margin: 20px 0; border-bottom: 2px solid #444; }
    .tab { flex: 1; padding: 15px; background: #333; border: none; color: #aaa; cursor: pointer; font-size: 16px; }
    .tab.active { background: #444; color: #fff; border-bottom: 3px solid #00ffff; }
    .tab-content { display: none; }
    .tab-content.active { display: block; }
    .footer {
      margin-top: 20px;
      font-size: 12px;
      color: #666;
    }
  </style>
  <script>
    function setMode(m) {
      fetch('/set?m=' + m);
    }
    function showTab(tabName) {
      var tabs = document.getElementsByClassName('tab-content');
      for (var i = 0; i < tabs.length; i++) {
        tabs[i].classList.remove('active');
      }
      var tabButtons = document.getElementsByClassName('tab');
      for (var i = 0; i < tabButtons.length; i++) {
        tabButtons[i].classList.remove('active');
      }
      document.getElementById(tabName).classList.add('active');
      event.target.classList.add('active');
    }
    function setLayout(layoutId) {
      fetch('/setLayout?layout=' + layoutId)
        .then(response => response.json())
        .then(data => {
          alert('Layout changed to: ' + data.layout);
          location.reload();  // Reload to refresh LED count
        });
    }
    window.onload = function() {
      // Set the layout dropdown to the current layout
      var layoutSelect = document.querySelector('select');
      if (layoutSelect) {
        layoutSelect.value = "%LAYOUT%";
      }
    }
  </script>
</head>
<body>
  <h1>LED Controller</h1>
  
  <div style="margin: 20px 0; padding: 15px; background: #333; border-radius: 8px;">
    <label style="color: #fff; font-size: 18px; margin-right: 10px;">Layout:</label>
    <select onchange="setLayout(this.value)" style="padding: 8px; font-size: 16px; background: #444; color: #fff; border: 1px solid #666; border-radius: 4px;">
      <option value="0">9x144 Row Zigzag (1296 LEDs)</option>
      <option value="1">8x32 Column Zigzag (256 LEDs)</option>
      <option value="2">32x32 Multi-Panel (1024 LEDs)</option>
    </select>
    <span style="color: #aaa; margin-left: 15px;">Active LEDs: %LEDS%</span>
  </div>


  <div class="control-group">
    <label>Panel Configuration (8x32 panels):</label>
    <form action="/setPanels" method="get" style="display:inline;">
      <label>Rows:</label>
      <input type="number" name="r" id="r" min="1" max="16" value="%ROWS%" style="width: 50px;">
      <label>Cols:</label>
      <input type="number" name="c" id="c" min="1" max="16" value="%COLS%" style="width: 50px;">
      <button type="submit" style="display:inline; width:auto; padding: 10px;">Set</button>
    </form>
    <br><small style="color:#aaa">Grid Size: (Cols*32) x (Rows*8)</small>
  </div>

  <div class="tabs">
    <button class="tab active" onclick="showTab('tab-patterns')">Patterns</button>
    <button class="tab" onclick="showTab('tab-text')">Scrolling Text</button>
  </div>

  <!-- Patterns Tab -->
  <div id="tab-patterns" class="tab-content active">
    <!-- Dynamic Menu Container -->
    <div id="patterns-container">
      <p style="color: #aaa; text-align: center;">Loading patterns...</p>
    </div>
  </div>

  <script>
    // Fetch and render patterns
    fetch('/api/patterns')
      .then(response => response.json())
      .then(patterns => {
        const container = document.getElementById('patterns-container');
        container.innerHTML = ''; // Clear loading message
        
        // Group by category
        const categories = {};
        patterns.forEach(p => {
          if (!categories[p.category]) categories[p.category] = [];
          categories[p.category].push(p);
        });
        
        // Render categories
        for (const [category, items] of Object.entries(categories)) {
          const groupDiv = document.createElement('div');
          groupDiv.className = 'control-group';
          
          const title = document.createElement('h3');
          title.textContent = category;
          groupDiv.appendChild(title);
          
          items.forEach(p => {
            const btn = document.createElement('button');
            btn.textContent = p.name;
            btn.onclick = () => setMode(p.id);
            
            // Assign random color class for variety
            const colors = ['cool', 'warm', 'special', 'fire', 'green', 'blue', 'rainbow', 'red'];
            const colorClass = colors[p.id % colors.length];
            btn.className = colorClass;
            
            groupDiv.appendChild(btn);
          });
          
          container.appendChild(groupDiv);
        }
      })
      .catch(err => {
        console.error('Error loading patterns:', err);
        document.getElementById('patterns-container').innerHTML = '<p style="color:red">Error loading patterns</p>';
      });
  </script>

  <!-- Scrolling Text Tab -->
  <div id="tab-text" class="tab-content">
    <h2>Scrolling Text</h2>
    <div class="control-group">
      <label>Enter text to scroll:</label>
      <div style="margin-top: 10px;">
        <input type="text" id="textInput" value="%TEXT%" style="width: 80%; padding: 10px; font-size: 16px;" maxlength="100">
        <button onclick="updateText()" style="width: 18%; padding: 10px;">Set</button>
      </div>

      <div style="margin-top: 15px;">
        <label>Scroll Speed: <span id="speedDisplay">%SPEED%</span></label><br>
        <input type="range" id="speedSlider" min="1" max="100" value="%SPEED%" style="width: 80%;"
               oninput="document.getElementById('speedDisplay').textContent = this.value"
               onchange="updateSpeed(this.value)">
        <br>
        <small style="color: #888;">1 = Slow, 100 = Fast</small>
      </div>
    </div>
    <p style="color: #aaa; font-size: 14px;">Supports: A-Z, 0-9, space, !, ., -</p>
  </div>

  <script>
    function updateText() {
      var text = document.getElementById('textInput').value;
      fetch('/setText?text=' + encodeURIComponent(text))
        .then(response => console.log('Text updated'));
    }

    function updateSpeed(speed) {
      fetch('/setText?speed=' + speed)
        .then(response => console.log('Speed updated'));
    }
  </script>


  <div class="footer">
    Build: %BUILD%
  </div>
</body>
</html>
)=====";

// The following server.on calls are typically placed in the setup() function.
// For the purpose of this edit, they are placed here as per the instruction's
// context. If this code is part of a larger sketch, ensure these are moved into
// setup().

void setupServerHandlers() { // Encapsulating the server.on calls in a function
                             // for syntactic correctness
  server.on("/setPanels", []() {
    String r = server.arg("r");
    String c = server.arg("c");

    int rows = 1;
    int cols = 1;

    // Default to current values if not provided
    if (panelsWide > 0) {
      cols = panelsWide;
      rows = (numPanels + panelsWide - 1) / panelsWide;
    }

    if (r.length() > 0) {
      int val = r.toInt();
      if (val >= 1 && val <= 16)
        rows = val;
    }

    if (c.length() > 0) {
      int val = c.toInt();
      if (val >= 1 && val <= 16)
        cols = val;
    }

    numPanels = rows * cols;
    panelsWide = cols;

    // Update Grid Dimensions for Multi-Panel Layout
    if (currentLayout == LAYOUT_32X32_MULTI_PANEL) {
      // Ensure valid width
      if (panelsWide > numPanels)
        panelsWide = numPanels;

      GRID_WIDTH = panelsWide * 32;
      int rows = (numPanels + panelsWide - 1) / panelsWide; // Ceiling division
      GRID_HEIGHT = rows * 8;

      activeLeds = numPanels * 256;
      if (activeLeds > MAX_LEDS)
        activeLeds = MAX_LEDS;
    }
    Serial.print("Panels: ");
    Serial.print(numPanels);
    Serial.print(", Wide: ");
    Serial.println(panelsWide);

    server.sendHeader("Location", "/");
    server.send(303);
  });

  server.on("/", []() {
    String html = FPSTR(htmlPage);
    int rows = (numPanels + panelsWide - 1) / panelsWide;
    html.replace("%ROWS%", String(rows));
    html.replace("%COLS%", String(panelsWide));
    html.replace("%LEDS%", String(activeLeds));
    // html.replace("%PANELS%", String(numPanels)); // Removed
    // html.replace("%WIDTH%", String(panelsWide)); // Removed
    html.replace("%LAYOUT%", String(currentLayout));
    html.replace("%TEXT%", scrollText);
    html.replace("%SPEED%", String(scrollSpeed));
    html.replace("%BUILD%", String(__DATE__) + " " + String(__TIME__));
    server.send(200, "text/html", html);
  });
}

// The original handleRoot() function is replaced by the server.on("/", ...)
// call above. If handleRoot() was called elsewhere, those calls will need to be
// updated.

void handleSet() {
  if (server.hasArg("m")) {
    currentPattern = server.arg("m").toInt();
    lastActivityTime = millis(); // User interaction resets timer
  }
  if (server.hasArg("c")) {
    int newCount = server.arg("c").toInt();
    if (newCount > 0 && newCount <= MAX_LEDS) {
      activeLeds = newCount;
      // Clear any LEDs that might be beyond the new count
      fill_solid(leds, MAX_LEDS, CRGB::Black);
      FastLED.show();
    }
  }
  server.send(200, "text/plain", "OK");
}

void handleSetLayout() {
  if (server.hasArg("layout")) {
    int newLayout = server.arg("layout").toInt();
    if (newLayout >= 0 && newLayout < 1) { // Only 1 layout now
      currentLayout = (LayoutType)newLayout;
      GRID_WIDTH = layouts[newLayout].width;
      GRID_HEIGHT = layouts[newLayout].height;

      // Always 1:1 spacing for Nx8x32
      LED_SPACING_H = 10.0;
      LED_SPACING_V = 10.0;
      ASPECT_RATIO = 1.0;

      // Clear LEDs
      fill_solid(leds, MAX_LEDS, CRGB::Black);
      FastLED.show();

      server.send(200, "application/json",
                  "{\"status\":\"success\",\"layout\":\"" +
                      String(layouts[newLayout].name) + "\"}");
    } else {
      server.send(400, "text/plain", "Invalid layout");
    }
  } else {
    server.send(400, "text/plain", "Missing layout parameter");
  }
}

void handleSetText() {
  if (server.hasArg("text")) {
    scrollText = server.arg("text");
    scrollText.toUpperCase(); // Convert to uppercase for font
    scrollOffset = 0;         // Reset scroll position
    currentPattern = 120;     // Switch to scrolling text mode
  }
  if (server.hasArg("speed")) {
    scrollSpeed = server.arg("speed").toInt();
    // Constrain to valid range
    if (scrollSpeed < 20)
      scrollSpeed = 20;
    if (scrollSpeed > 200)
      scrollSpeed = 200;
  }
  server.sendHeader("Location", "/");
  server.send(303); // Redirect back to main page
}
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
void loop() {
  // State Machine Logic
  if (currentPattern == 200) {
    if (millis() - lastActivityTime > IDLE_TIMEOUT) {
      Serial.println("Idle timeout -> Switching to Streaming Mode");
      currentPattern = 255;
      lastUdpPacketTime = millis();
    }
  }

  // Streaming optimization: skip HTTP/OTA during active streaming
  bool inStreaming = (currentPattern == 255);
  // Relaxed check: Check HTTP every 200ms even if streaming
  static unsigned long lastHttpCheck = 0;
  if (!inStreaming || (millis() - lastHttpCheck > 200)) {
    ArduinoOTA.handle();
    server.handleClient();
    lastHttpCheck = millis();
  }

  // Auto-exit streaming if no UDP for 5 seconds -> REMOVED per request
  // if (inStreaming && millis() - lastUdpPacketTime > 5000) {
  //   currentPattern = 0;
  // }

  // UDP Streaming - only process if in streaming mode
  if (inStreaming) {
    int packetSize;
    while ((packetSize = udp.parsePacket())) {
      // Check for EXIT magic packet (4 bytes)
      if (packetSize == 4) {
        char buf[5] = {0};
        udp.read(buf, 4);
        if (memcmp(buf, "EXIT", 4) == 0) {
          Serial.println("UDP EXIT received -> Returning to Idle");
          currentPattern = 200;        // Return to IP+Clock
          lastActivityTime = millis(); // Reset idle timer
          break;
        }
        // Not EXIT, treat as small data (unlikely for LED data)
      } else {
        // Normal LED data packet
        udp.read((char *)leds, min(packetSize, (int)(MAX_LEDS * sizeof(CRGB))));
        FastLED.show();
        lastUdpPacketTime = millis();
        udpPacketsReceived++;
        udpPacketsDisplayed++;
      }
    }
  }

  // Non-blocking animation (only when not streaming)
  if (currentPattern != 255) {
    EVERY_N_MILLISECONDS(20) {
      if (!serverRunning) {
        // Flash red to indicate server not up
        static bool flashState = false;
        fill_solid(leds, MAX_LEDS, flashState ? CRGB::Red : CRGB::Black);
        flashState = !flashState;
        FastLED.show();
        return;
      }

      renderPatternFrame(currentPattern, leds, activeLeds, hue, scrollText,
                         scrollOffset, scrollSpeed);
      FastLED.show();
    }
  }
}

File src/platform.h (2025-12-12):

#ifndef PLATFORM_H
#define PLATFORM_H

#ifdef SIMULATOR
// Simulator platform (native C++)
#include <cmath>
#include <cstdint>
#include <cstdlib>
#include <cstring>

// Mock PROGMEM for simulator
#define PROGMEM
#define pgm_read_byte(addr) (*(const uint8_t *)(addr))

// Mock millis() for simulator
#include <chrono>
#ifdef SIM_WASM
extern unsigned long (*sim_millis_fn)();
#endif

inline unsigned long millis() {
#ifdef SIM_WASM
  if (sim_millis_fn) {
    return sim_millis_fn();
  }
#endif
  static auto start = std::chrono::steady_clock::now();
  auto now = std::chrono::steady_clock::now();
  return std::chrono::duration_cast<std::chrono::milliseconds>(now - start)
      .count();
}

// Timer helpers (lightweight stand-ins for FastLED EVERY_N_* macros)
#ifndef EVERY_N_MILLISECONDS
#define _EVERY_N_HELPER(token, interval_ms)                                    \
  for (static unsigned long _last_##token = 0;                                 \
       ((millis() - _last_##token) >= (interval_ms))                           \
           ? (_last_##token = millis(), true)                                  \
           : false;)
#define EVERY_N_MILLISECONDS(x) _EVERY_N_HELPER(__LINE__, (x))
#define EVERY_N_SECONDS(x) _EVERY_N_HELPER(__LINE__, (uint32_t)(x) * 1000UL)
#endif

// Mock random for simulator
inline uint8_t random8() { return rand() % 256; }

inline uint8_t random8(uint8_t lim) { return rand() % lim; }

inline uint8_t random8(uint8_t min, uint8_t max) {
  return min + (rand() % (max - min));
}

inline uint16_t random16() { return rand() % 65536; }

inline uint16_t random16(uint16_t lim) { return rand() % lim; }

// Arduino-compatible aliases
using byte = uint8_t;

#else
// ESP8266 platform
#include <Arduino.h>
#include <FastLED.h>

// Arduino provides these already

#endif

// Common types and constants (work on both platforms)
#define MAX_LEDS 2048
// Grid configuration is now in main.cpp as runtime variables
// to support multiple layout presets (see main.cpp for LayoutType enum)
extern int GRID_WIDTH;
extern int GRID_HEIGHT;
extern float LED_SPACING_H;
extern float LED_SPACING_V;
extern float ASPECT_RATIO;
// CRGB type for both platforms
#ifndef SIMULATOR
// Use FastLED's CRGB
// (already included above)
#else
// Define our own CRGB for simulator
struct CRGB {
  uint8_t r;
  uint8_t g;
  uint8_t b;

  CRGB() : r(0), g(0), b(0) {}
  CRGB(uint8_t r, uint8_t g, uint8_t b) : r(r), g(g), b(b) {}

  inline void fadeToBlackBy(uint8_t amount) {
    r = (amount > r) ? 0 : static_cast<uint8_t>(r - amount);
    g = (amount > g) ? 0 : static_cast<uint8_t>(g - amount);
    b = (amount > b) ? 0 : static_cast<uint8_t>(b - amount);
  }

  // Named colors
  static const CRGB Black;
  static const CRGB Red;
  static const CRGB Green;
  static const CRGB Blue;
  static const CRGB Yellow;
  static const CRGB Orange;
  static const CRGB Purple;
  static const CRGB Cyan;
  static const CRGB Magenta;
  static const CRGB White;
};

// Define named colors
inline const CRGB CRGB::Black = CRGB(0, 0, 0);
inline const CRGB CRGB::Red = CRGB(255, 0, 0);
inline const CRGB CRGB::Green = CRGB(0, 255, 0);
inline const CRGB CRGB::Blue = CRGB(0, 0, 255);
inline const CRGB CRGB::Yellow = CRGB(255, 255, 0);
inline const CRGB CRGB::Orange = CRGB(255, 165, 0);
inline const CRGB CRGB::Purple = CRGB(128, 0, 128);
inline const CRGB CRGB::Cyan = CRGB(0, 255, 255);
inline const CRGB CRGB::Magenta = CRGB(255, 0, 255);
inline const CRGB CRGB::White = CRGB(255, 255, 255);

// CHSV to RGB conversion
inline CRGB CHSV(uint8_t h, uint8_t s, uint8_t v) {
  float hue = h / 255.0f;
  float sat = s / 255.0f;
  float val = v / 255.0f;

  float r, g, b;
  int i = (int)(hue * 6);
  float f = hue * 6 - i;
  float p = val * (1 - sat);
  float q = val * (1 - f * sat);
  float t = val * (1 - (1 - f) * sat);

  switch (i % 6) {
  case 0:
    r = val;
    g = t;
    b = p;
    break;
  case 1:
    r = q;
    g = val;
    b = p;
    break;
  case 2:
    r = p;
    g = val;
    b = t;
    break;
  case 3:
    r = p;
    g = q;
    b = val;
    break;
  case 4:
    r = t;
    g = p;
    b = val;
    break;
  case 5:
    r = val;
    g = p;
    b = q;
    break;
  }

  return CRGB(r * 255, g * 255, b * 255);
}

// FastLED helper functions
inline uint8_t sin8(uint8_t theta) {
  return (sin(theta * M_PI / 128.0) + 1.0) * 127.5;
}

inline uint8_t cos8(uint8_t theta) {
  return (cos(theta * M_PI / 128.0) + 1.0) * 127.5;
}

inline uint8_t beatsin8(uint8_t bpm, uint8_t lowest = 0, uint8_t highest = 255,
                        uint32_t timebase = 0, uint8_t phase_offset = 0) {
  uint32_t ms = millis() + timebase;
  uint16_t beats = (ms * bpm) / 60000;
  uint8_t phase = (beats & 0xFF) + phase_offset;
  uint8_t sinval = sin8(phase);
  return lowest + ((sinval * (highest - lowest)) >> 8);
}

inline uint16_t beatsin16(uint16_t bpm, uint16_t lowest = 0,
                          uint16_t highest = 65535, uint32_t timebase = 0,
                          uint16_t phase_offset = 0) {
  return beatsin8(bpm, lowest >> 8, highest >> 8, timebase, phase_offset >> 8)
         << 8;
}

inline uint8_t qadd8(uint8_t a, uint8_t b) {
  unsigned int sum = a + b;
  if (sum > 255)
    sum = 255;
  return sum;
}

inline uint8_t qsub8(uint8_t a, uint8_t b) {
  if (a < b)
    return 0;
  return a - b;
}

inline void fill_solid(CRGB *leds, int numLeds, const CRGB &color) {
  for (int i = 0; i < numLeds; i++) {
    leds[i] = color;
  }
}

inline void fadeToBlackBy(CRGB *leds, int numLeds, uint8_t amount) {
  for (int i = 0; i < numLeds; i++) {
    leds[i].r = qsub8(leds[i].r, amount);
    leds[i].g = qsub8(leds[i].g, amount);
    leds[i].b = qsub8(leds[i].b, amount);
  }
}

inline CRGB HeatColor(uint8_t temperature) {
  // Heat ramp: black -> red -> yellow -> white
  uint8_t t192 = (temperature * 191) / 255;
  uint8_t heatramp = t192 & 0x3F;
  heatramp <<= 2;

  if (t192 & 0x80) {
    return CRGB(255, 255, heatramp);
  } else if (t192 & 0x40) {
    return CRGB(255, heatramp, 0);
  } else {
    return CRGB(heatramp, 0, 0);
  }
}

inline uint8_t inoise8(uint16_t x, uint16_t y = 0, uint16_t z = 0) {
  // Simplified noise function
  float nx = x * 0.01f;
  float ny = y * 0.01f;
  float nz = z * 0.01f;
  float n = sin(nx) * cos(ny) * sin(nz);
  return ((n + 1.0f) * 0.5f) * 255;
}

inline void blur1d(CRGB *leds, int numLeds, uint8_t amount) {
  // Simple 3-point blur
  for (int i = 1; i < numLeds - 1; i++) {
    leds[i].r = (leds[i - 1].r + leds[i].r + leds[i + 1].r) / 3;
    leds[i].g = (leds[i - 1].g + leds[i].g + leds[i + 1].g) / 3;
    leds[i].b = (leds[i - 1].b + leds[i].b + leds[i + 1].b) / 3;
  }
}
#endif

#endif // PLATFORM_H

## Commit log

2025-11-23 Add serial upload support and increase LED capacity to 1500
    - Add d1_mini_serial environment for USB serial uploads via esptool
    - Fix device.sh to use serial environment instead of OTA for USB uploads
    - Increase MAX_LEDS from 200 to 1500 to support 9 strips (1296 LEDs)
    - Set default activeLeds to 1296 (9 strips × 144 LEDs each)
    - Update web UI to allow setting up to 1500 LEDs
    - Add early serial debug output before WiFi connection
    - Display WiFi credentials and connection status during boot
    - Show connection attempts counter for debugging
    - Add baudrate detection helper scripts for debugging serial issues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
    [main.cpp]
2025-11-23 Tweak test-card pattern and document LED usage
2025-11-23 Render simulator LEDs with real strip spacing
2025-11-23 Add LED pattern designer web app with custom pattern upload
    Features:
    - Cross-platform touch/mouse drawing interface (144×9 grid)
    - Sparse data format for efficient pattern uploads
    - Custom pattern mode (122) on ESP8266
    - Fixed heart and Christmas tree ASCII patterns for correct orientation
    - Web-based pattern designer with debug logging
    Changes:
    - src/main.cpp: Add /uploadPattern endpoint and pattern mode 122
    - src/patterns/font.cpp: Fix heart (<) and tree (>) bitmaps
    - web/: New pattern designer web app with logging server
    - sim/wasm/index.html: Minor WASM updates
    [main.cpp]
2025-11-24 Add Mechanical
    [full_assembly.stl, led_strip_holder.scad, module_25mm_middle.stl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]
2025-12-12 Add mechanical updates and other changes
    [8x32_VISUALIZATION.scad, 8x32_housing_1.3mf, 8x32_housing_left.3mf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]
2025-12-12 Project Cleanup, Mechanical Updates, and API Fixes
    [8x32_VISUALIZATION.scad, 8x32_housing.scad, 8x32_housing_1.3mf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]
2025-12-14 Fix pattern designer upload, rendering logic, and add IP clock pattern
    [main.cpp]
2025-12-15 Optimize ESP8266 streaming: 2x faster FastLED, HTTP enter/UDP exit state machine, 24 FPS audio visualizer
    - Fixed FastLED to use 1024 LEDs instead of 2048 (68ms -> 32ms)
    - Added /stream HTTP endpoint to enter streaming mode
    - Added UDP EXIT magic packet to exit streaming mode
    - Simplified UDP loop (no drain, received == displayed)
    - Optimized Makefile upload-ota with 6s streaming exit delay
    - Added /timing endpoint for profiling
    - Reduced visualizer FPS from 94 to 24 for perfect sync
    - Added per-band auto-normalization in FFT
    - Added amplitude scaling (0.8x)
    [main.cpp]
2025-12-15 Improve FFT frequency mapping: 40Hz-16kHz range, nearest-bin fallback for sparse bins
2025-12-15 Add visualization modes with live keyboard switching
    - 3 modes: bars (default), mirror, wave
    - Keyboard shortcuts: 1=bars, 2=mirror, 3=wave, q=quit
    - Improved wave mode with smooth sine pattern
    - 40Hz-16kHz frequency range with nearest-bin fallback
    - Per-band auto-normalization and peak hold
2025-12-18 Add FPS display to visualizer and fix serial upload permissions
    - lowlatency_visualizer.py: Add real-time FPS counter (shows FPS every second)
    - scripts/device.sh: Separate build from upload, use sudo only for esptool flash
    - Build runs as normal user (no package re-downloads)
    - Flash uses sudo python3 esptool.py for serial port access
2025-12-18 Add WiFi stability improvements and RSSI display to Pattern 200
    Firmware (main.cpp):
    - WiFi.setSleepMode(WIFI_NONE_SLEEP) for better stability
    - WiFi.setAutoReconnect(true) for auto-reconnection
    - Move configTime() after WiFi connects (fixes NTP sync)
    - Add NTP sync wait on startup (up to 10 seconds)
    - Print RSSI to serial on boot
    Pattern 200 (pattern_200_ip_clock.cpp):
    - Panel 3: 5-bar WiFi signal strength indicator (green/yellow/red)
    - Panel 4: RSSI value in dBm
    [main.cpp]
